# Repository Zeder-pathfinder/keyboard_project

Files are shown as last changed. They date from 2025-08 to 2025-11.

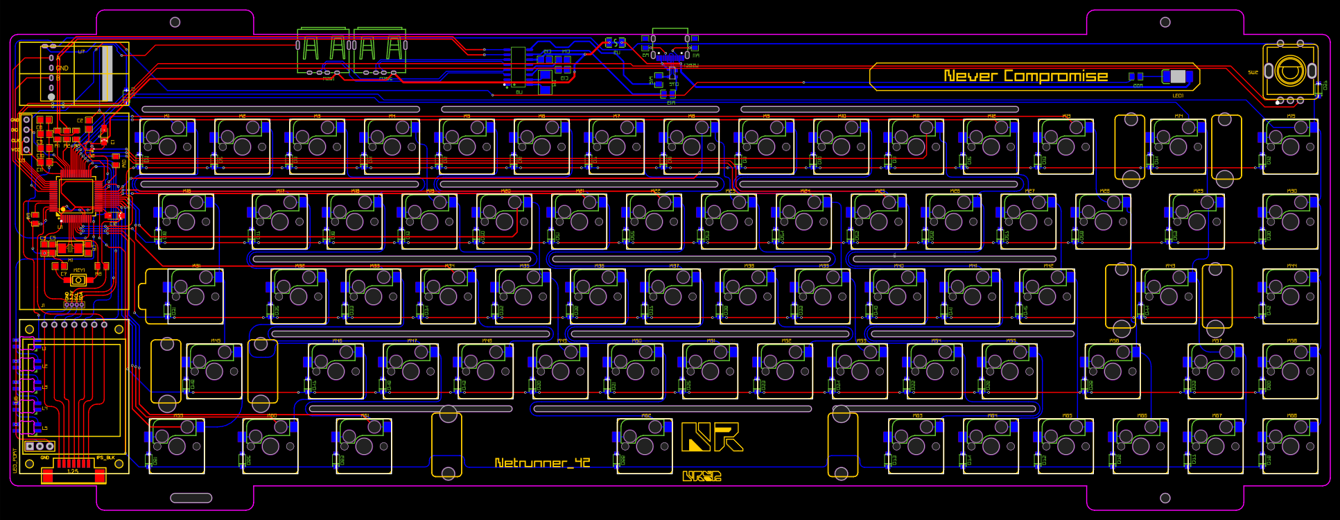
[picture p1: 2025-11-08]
PCB_design/stm32KBD_PCB.png

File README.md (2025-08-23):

# keyboard_project
这个项目是我的一个大学毕业设计。
This project was my university graduation design. 

固件使用的是QMK，但是屏幕的点亮和其它UI设计我不会了，所以烂尾了。
The firmware uses QMK, but I don't know how to light up the screen or do other UI designs, so it ended up unfinished. 

其它功能都是好的，比如键盘上的旋钮，灯光，以及按键。
All other functions work fine，for example, the knobs, lights, and buttons on the keyboard.

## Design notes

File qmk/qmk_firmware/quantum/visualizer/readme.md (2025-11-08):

# A visualization library for the TMK keyboard firmware

This library is designed to work together with the [TMK keyboard firmware](https://github.com/tmk/tmk_keyboard). Currently it only works for [Chibios](http://www.chibios.org/)
 flavors, but it would be possible to add support for other configurations as well. The LCD display functionality is provided by the [uGFX library](http://www.ugfx.org/). 

## To use this library as a user
You can and should modify the visualizer\_user.c file. Check the comments in the file for more information.

## To add this library to custom keyboard projects

1. Add tmk_visualizer as a submodule to your project
1. Set VISUALIZER_DIR in the main keyboard project makefile to point to the submodule
1. Define LCD\_ENABLE and/or LCD\_BACKLIGHT\_ENABLE, to enable support
1. Include the visualizer.mk make file
1. Copy the files in the example\_integration folder to your keyboard project
1. All other files than the callback.c file are included automatically, so you will need to add callback.c to your makefile manually. If you already have a similar file in your project, you can just copy the functions instead of the whole file.
1. Edit the files to match your hardware. You might might want to read the Chibios and UGfx documentation, for more information.
1. If you enable LCD support you might also have to write a custom uGFX display driver, check the uGFX documentation for that. You probably also want to enable SPI support in your Chibios configuration.

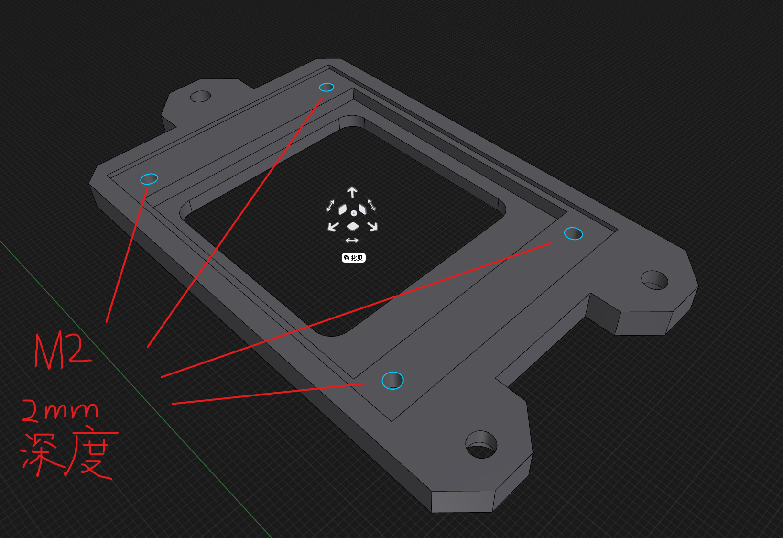
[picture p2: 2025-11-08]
keyboard_model/Screw hole design/Screen bracket screw holes.png

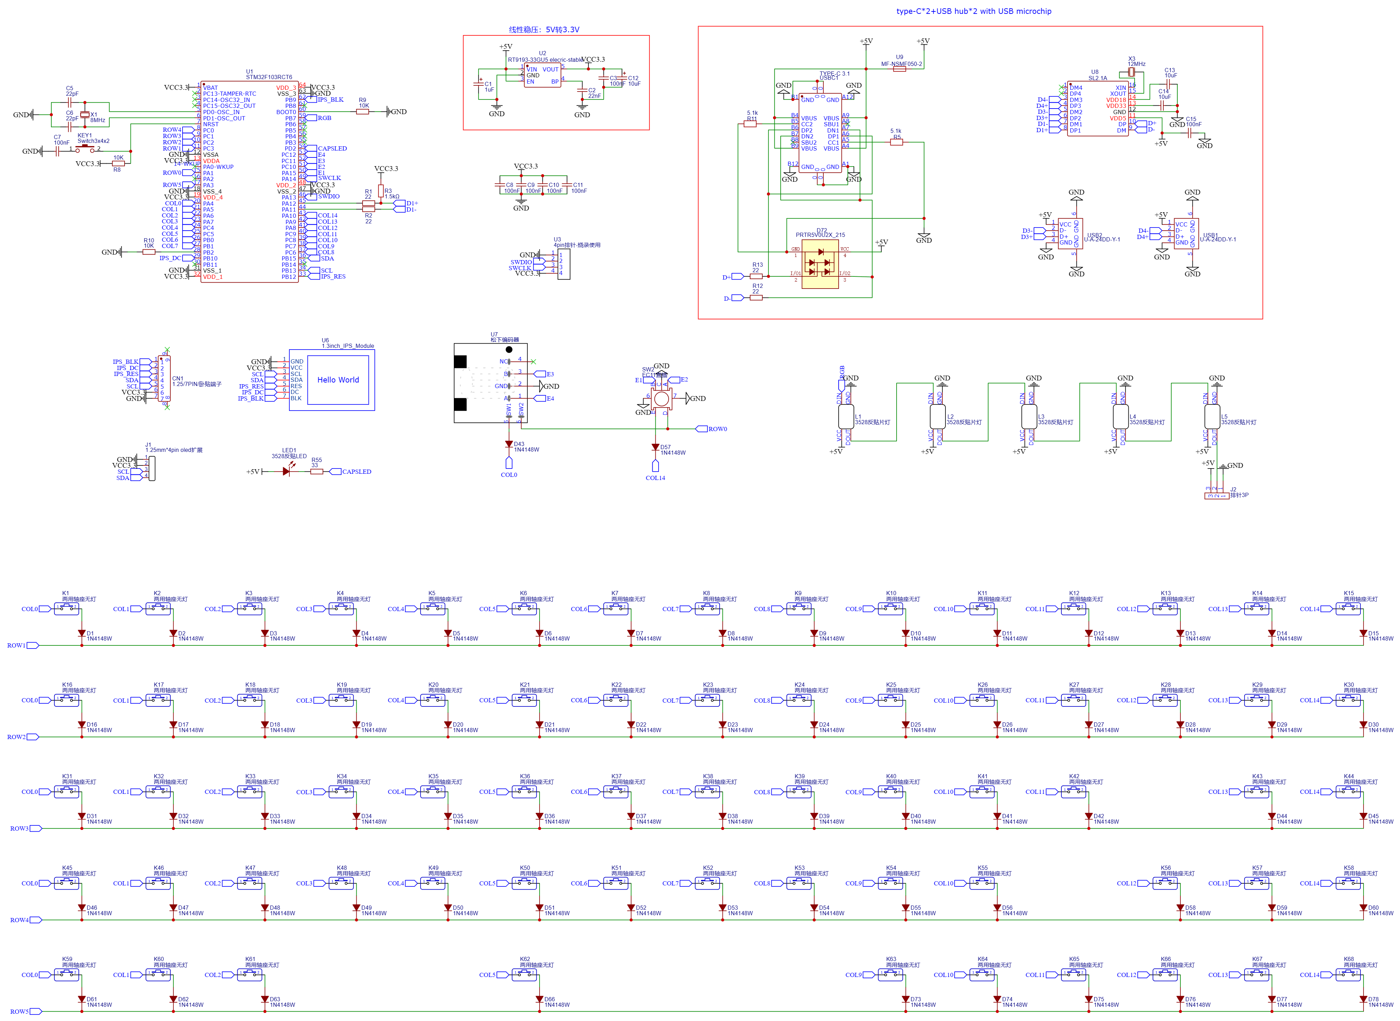
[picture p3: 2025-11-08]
PCB_design/Schematic_netrunner42_stm32_KB_2023-11-25.png

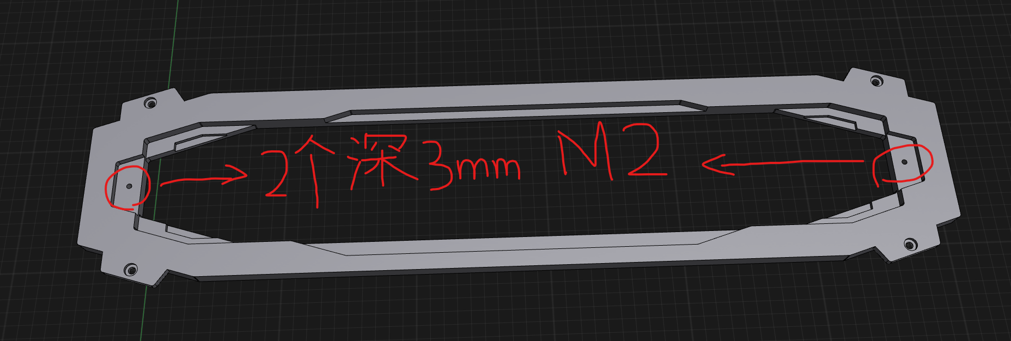
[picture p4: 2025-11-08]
keyboard_model/Screw hole design/Lower display cover hole position.png

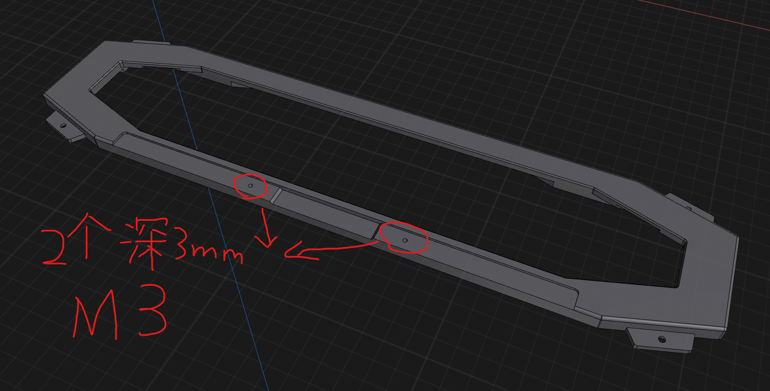
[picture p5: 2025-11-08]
keyboard_model/Screw hole design/bracket screw.png

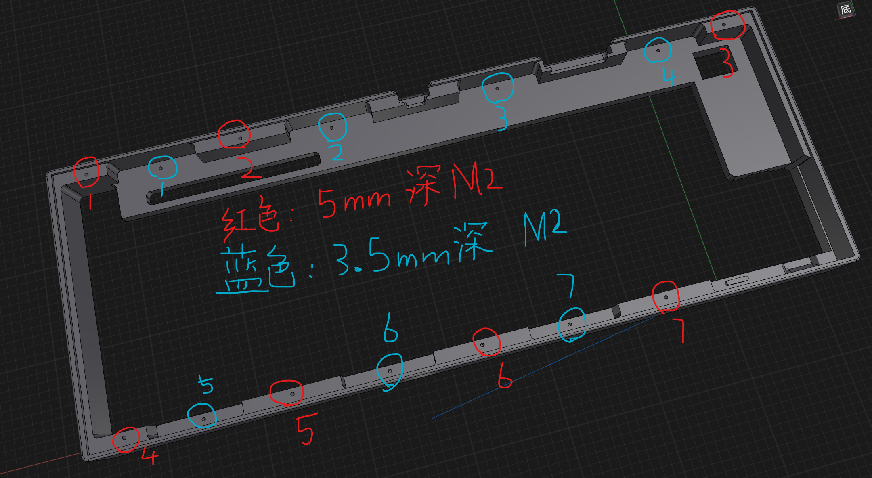
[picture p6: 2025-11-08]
keyboard_model/Screw hole design/Screw hole positions on the bottom of the shell.png

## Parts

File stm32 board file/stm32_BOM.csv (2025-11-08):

ID | Name | Designator | Footprint | Quantity | Manufacturer Part | Manufacturer | Supplier | Supplier Part | Price
1 | 1N4148W | D43,D44,D45,D46,D47,D48,D49,D50,D51,D52,D53,D54,D55,D56,D57,D58,D59,D60,D61,D62,D63,D66,D73,D74,D75,D76,D77,D78,D1,D2,D3,D4,D5,D6,D7,D8,D9,D10,D11,D12,D13,D14,D15,D16,D17,D18,D19,D20,D21,D22,D23,D24,D25,D26,D27,D28,D29,D30,D31,D32,D33,D34,D35,D36,D37,D38,D39,D40,D41,D42 | SOD-123_L2.8-W1.8-LS3.7-RD | 70 | 1N4148W | HT(金誉) | LCSC | C179717 | 0.067
2 | 10uF | C13,C14 | C0805 | 2 | 0805X106K250NT | FH | LCSC | C40894 | 0.084
3 | 100nF | C15 | C0805 | 1 | CC0805KRX7R9BB104 | YAGEO | LCSC | C49678 | 0.0292
4 | PRTR5V0U2X_215 | D72 | 1727-3884-1-ND | 1 | PRTR5V0U2X,215 | Nexperia USA Inc. | DigiKey | 1727-3884-1-ND
5 | 5.1k | R5,R11 | 0805 | 2 | AR06BTCV5101 | Viking Tech | LCSC | C319569 | 0.4251
6 | 22 | R12,R13 | 0805 | 2 | 1206W4F680JT5E |  | Digi-Key | RTAN1206BKE22R0CT-ND
7 | SL2.1A | U8 | SOP-16_L10.0-W3.9-P1.27-LS6.0-BL | 1 | SL2.1A | CoreChips | LCSC | C192893 | 1.4777
8 | MF-NSMF050-2 | U9 | F1206 | 1 | MF-NSMF050-2 | BOURNS | LCSC | C75464 | 0.1672
9 | U-A-24DD-Y-1 | USB1,USB2 | USB-A-TH_U-A-24DD-Y-1 | 2 | U-A-24DD-Y-1 | Rectangular Connectors - Contacts | LCSC | C193133 | 0.8369
10 | 12MHz | X3 | OSC-SMD_2P-L5.0-W3.2 | 1 | 6I12000F20UCG | SHENZHEN CRYSTAL TECH | LCSC | C251588 | 1.7048
11 | TYPE-C 3.1 | USBC1 | USB-C_SMD-TYPE-C-31-M-12 | 1 | - | LCSC | LCSC | C168689 | 3.15
12 | 33 | R55 | R0805 | 1 | RC0805JR-0733RL | YAGEO | LCSC | C127988 | 0.0131
13 | 排针3P | LED_PORT | 排针3P | 1
14 | 3528反贴片灯 | L1,L2,L3,L4,L5 | 凯华RGB | 5
15 | 两用轴座无灯 | K1,K2,K3,K4,K5,K6,K7,K8,K9,K10,K11,K12,K13,K14,K15,K16,K17,K18,K19,K20,K21,K22,K23,K24,K25,K26,K27,K28,K29,K30,K31,K32,K33,K34,K35,K36,K37,K38,K39,K40,K41,K42,K43,K44,K45,K46,K47,K48,K49,K50,K51,K52,K53,K54,K55,K56,K57,K58,K59,K60,K61,K62,K63,K64,K65,K66,K67,K68 | 两用轴座无灯 | 68
16 | 1.3inch_IPS_Module | U6 | 1.3INCH IPS MODULE | 1
17 | 1.25/7PIN/卧贴端子 | CN1 | 1.25/7PIN/卧贴端子 | 1
18 | 1.25mm*4pin oled扩展 | J1 | 1.25*4PIN | 1
19 | STM32F103RCT6 | U1 | LQFP-64_L10.0-W10.0-P0.50-LS12.0-BL | 1 | STM32F103RCT6 | ST(意法半导体) | LCSC | C8323 | 12.06
20 | 4pin排针-烧录使用 | U3 | 4PIN排针 | 1
21 | 松下编码器 | U7 | EVQWGD001 | 1 | EVQWGD001 | panasonic | 77lp | EVQWGD001
22 | 1.5kΩ | R3 | R0805 | 1 | RMC08051.5K1%N | Tyohm(幸亚电阻) | LCSC | C269739 | 0.0309
23 | 3528反贴LED | LED1 | 3528反贴LED | 1 | 204-10SURD/S530-A3 | EVERLIGHT | LCSC | C99772 | 0.1792
24 | EC11直插 | SW2 | SW-TH_EC11E15244G1 | 1 | EC11E15244G1 | ALPS Electric | LCSC | C370970 | 11.73
25 | 1uF | C1 | CAP-SMD_L3.2-W1.6-RD | 1 | TAJA105K025RNJ | AVX | LCSC | C7175 | 0.6411
26 | 22 | R1,R2 | R0805 | 2 | RC0805FR-0722RL | YAGEO | LCSC | C107702 | 0.0128
27 | 8MHz | X1 | CRYSTAL-SMD_L5.0-W3.2 | 1 | X50328MSB2GI | YXC | LCSC | C115962 | 1.1309
28 | 22nF | C2 | C0805 | 1 | CL21B223KBANNNC | SAMSUNG | LCSC | C1729 | 0.0579
29 | 100nF | C3,C7,C8,C9,C10,C11 | C0805 | 6 | CL21B104KBCNNNC | SAMSUNG | LCSC | C1711 | 0.0335
30 | 22pF | C5,C6 | C0805 | 2 | 0805CG220J500NT | FH | LCSC | C38143 | 0.0986
31 | 10uF | C12 | CAP-SMD_L3.2-W1.6-RD | 1 | TAJA106M016RNJ | AVX | LCSC | C8015 | 0.6834
32 | Switch3x4x2 | KEY1 | KEY-3.0*4.0 | 1 | Switch3x4x2 | ReliaPro | LCSC | C26638 | 0.2594
33 | 10K | R8,R9,R10 | R0805 | 3 | RC0805FR-0710KL | YAGEO | LCSC | C84376 | 0.013
34 | RT9193-33GU5 elecric-stable | U2 | SC-70-5_L2.1-W1.3-P0.65-LS2.1-BL | 1 | RT9193-33GU5 | Richtek Tech | LCSC | C425797 | 1.2439

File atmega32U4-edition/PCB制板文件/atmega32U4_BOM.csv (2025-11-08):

ID | Name | Designator | Footprint | Quantity | Manufacturer Part | Manufacturer | Supplier | Supplier Part | Price
1 | 22pF | C1,C2 | C0805 | 2 | 0805CG220J500NT | FH | LCSC | C38143 | 0.0986
2 | 1uF | C3 | C0805 | 1 | CL21B105KBFNFNE | SAMSUNG(三星) | LCSC | C318709 | 0.089
3 | 470nF | C8 | C0805 | 1 | 0805B474K500NT | FH(风华) | LCSC | C49955 | 0.0755
4 | 1N4148W | D2,D3,D4,D5,D6,D7,D8,D9,D10,D11,D12,D13,D14,D15,D16,D17,D18,D19,D20,D21,D22,D23,D24,D25,D26,D27,D28,D29,D30,D31,D32,D33,D34,D35,D36,D37,D38,D39,D40,D41,D42,D43,D44,D45,D46,D47,D48,D49,D50,D51,D52,D53,D54,D55,D56,D57,D58,D59,D60,D61,D62,D63,D64,D65,D66,D67,D68,D69 | SOD-123_L2.8-W1.8-LS3.7-RD | 68 | 1N4148W | HT(金誉) | LCSC | C179717 | 0.067
5 | 10kΩ | R1,R2 | R0805 | 2 | RC0805FR-0710KL | YAGEO(国巨) | LCSC | C84376 | 0.013
6 | 22 | R3,R4 | R0805 | 2 | RC0805FR-0722RL | YAGEO(国巨) | LCSC | C107702 | 0.0128
7 | 5.1K | R6,R7 | R0805 | 2 | RC0805FR-075K1L | YAGEO(国巨) | LCSC | C84375 | 0.0124
8 | TYPE-C-31-M-12 | USBC1 | USB-C_SMD-TYPE-C-31-M-12 | 1 | TYPE-C-31-M-12 | 韩国韩荣 | LCSC | C165948 | 1.0354
9 | 16MHZ | X1 | OSC-SMD_2P-L5.0-W3.2 | 1 | XSHEELNANF-16MHZ | TAITIEN(泰艺电子) | LCSC | C242221 | 2.0561
10 | 100nF | C4,C5,C6,C7 | C0805 | 4 | 0805B104J500NT | FH(风华) | LCSC | C29926 | 0.0506
11 | ATMEGA32U4-AU | MAIN | QFP-44_L10.0-W10.0-P0.80-LS13.2-BL | 1 | ATMEGA32U4-AU | MICROCHIP(美国微芯) | LCSC | C44854 | 35.32
12 | Switch3x4x2 | KEY1 | SW-SMD_L4.0-W2.9-LS5.0 | 1 | 轻触开关3x4x2 | 国产 | LCSC | C26638 | 0.2594
13 | 排针3P | J1 | 排针3P | 1
14 | PCB卫星轴_2.25U | U2,U3,U4 | PCB卫星轴__2.25U | 3
15 | ws2812b-3535 | U5 | WS2812B-3535 | 1

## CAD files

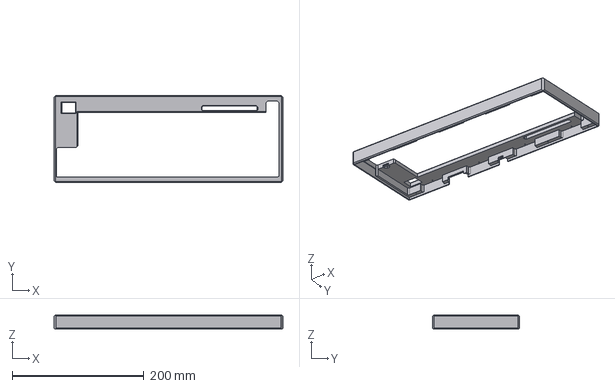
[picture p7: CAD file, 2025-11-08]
atmega32U4-edition/3D打印外壳/upshell.step
347.9 x 132.9 x 21.5 mm

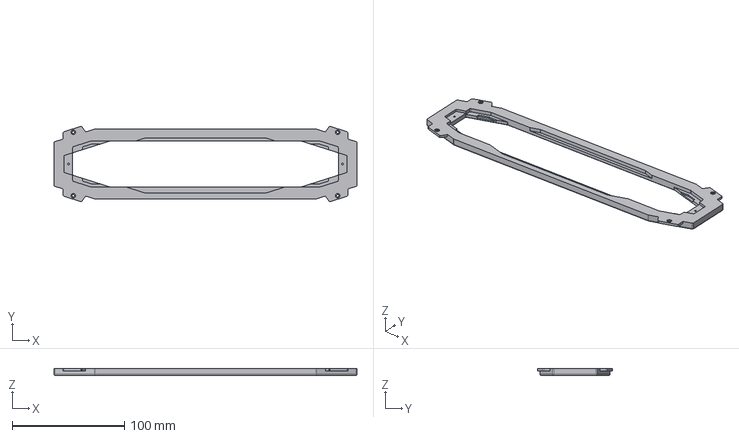
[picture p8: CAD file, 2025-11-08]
keyboard_model/shell2.step
269.7 x 67.1 x 6.00 mm

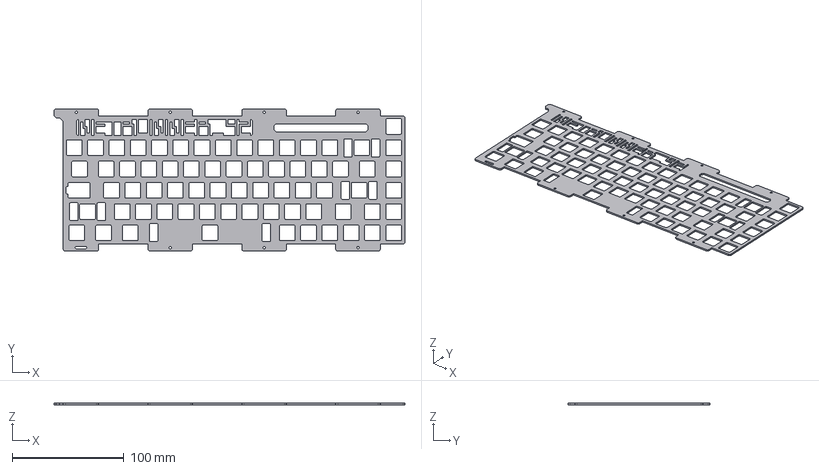
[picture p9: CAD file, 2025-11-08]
atmega32U4-edition/3D打印外壳/plate.step
314.0 x 127.3 x 1.50 mm

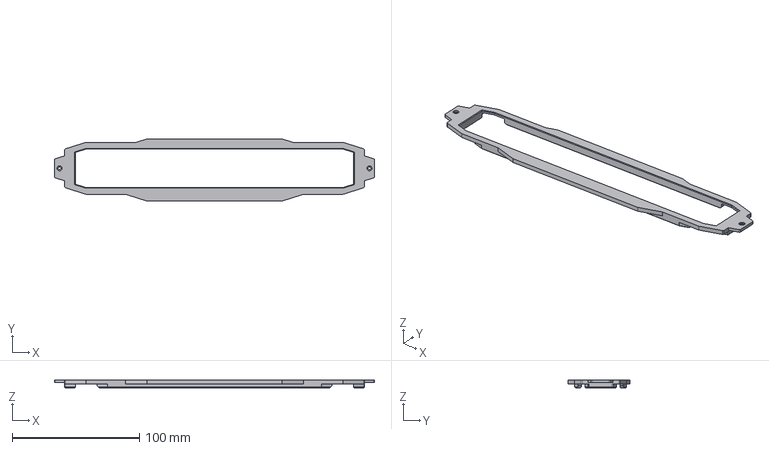
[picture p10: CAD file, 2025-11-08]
keyboard_model/logoshell.step
251.9 x 48.9 x 6.00 mm

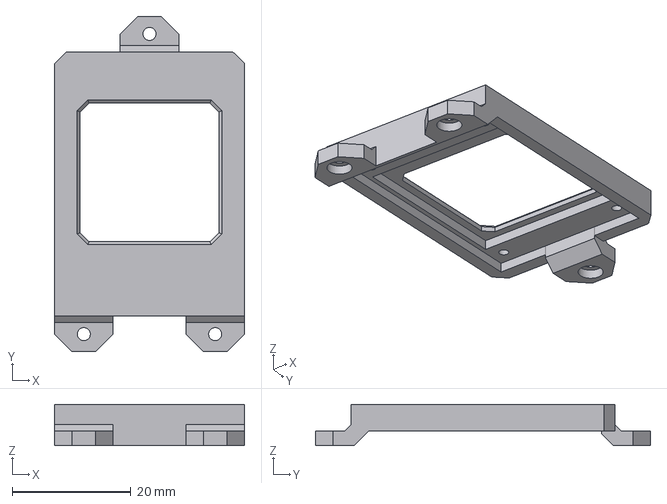
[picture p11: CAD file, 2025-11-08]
atmega32U4-edition/3D打印外壳/screen.step
32.1 x 56.6 x 7.00 mm

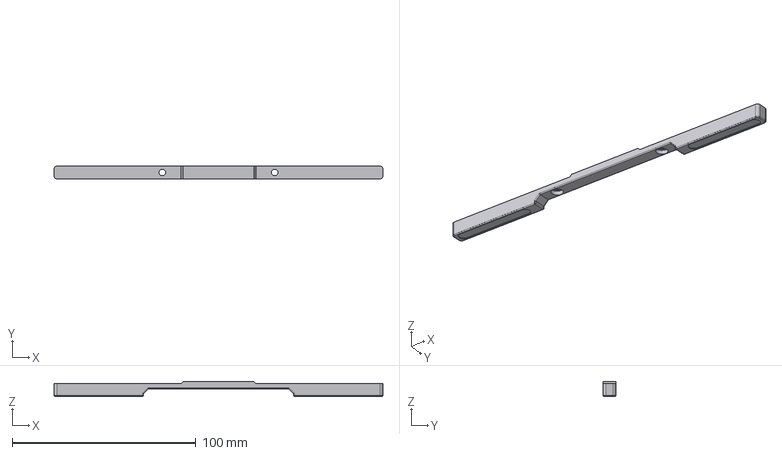
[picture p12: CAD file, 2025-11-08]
keyboard_model/stand.step
179.3 x 6.92 x 8.00 mm

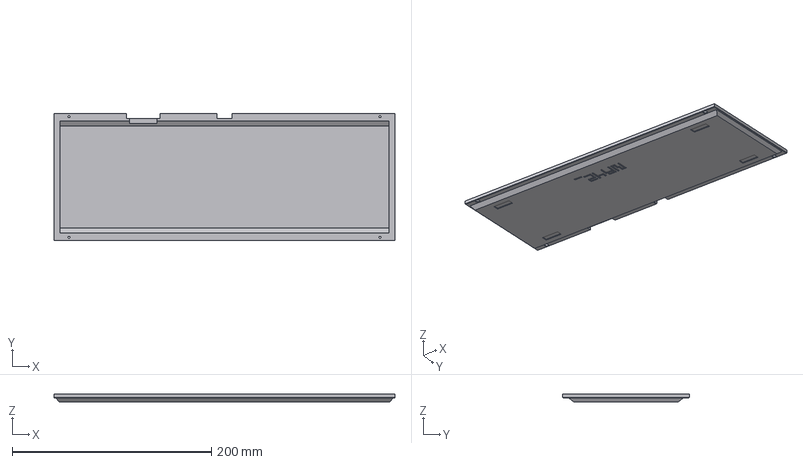
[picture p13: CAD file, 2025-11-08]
atmega32U4-edition/3D打印外壳/downshell.step
341.9 x 127.3 x 8.00 mm

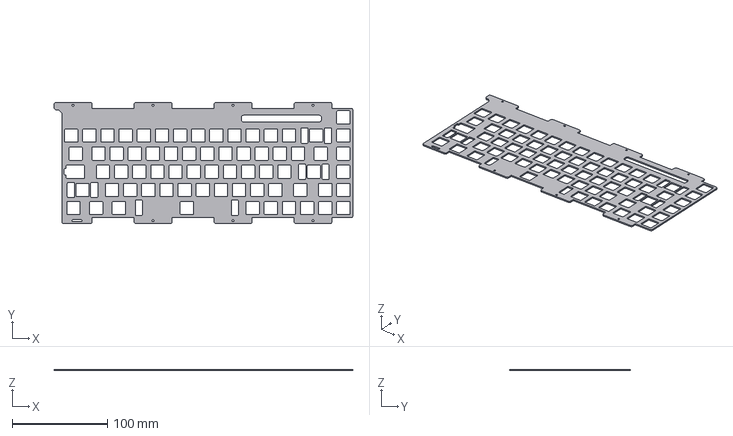
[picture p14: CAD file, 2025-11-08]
keyboard_model/plate.step
314.0 x 127.3 x 1.50 mm

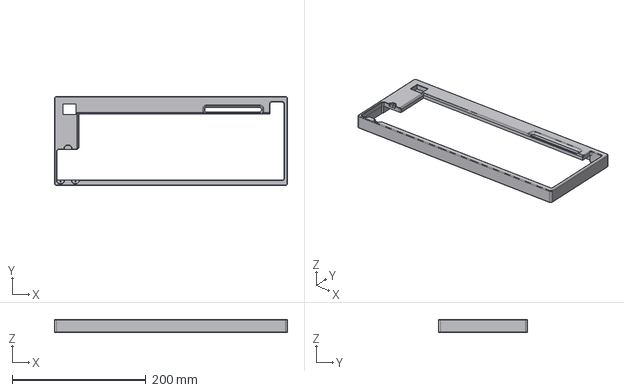
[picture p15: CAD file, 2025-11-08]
keyboard_model/upshell.step
347.9 x 132.9 x 19.5 mm

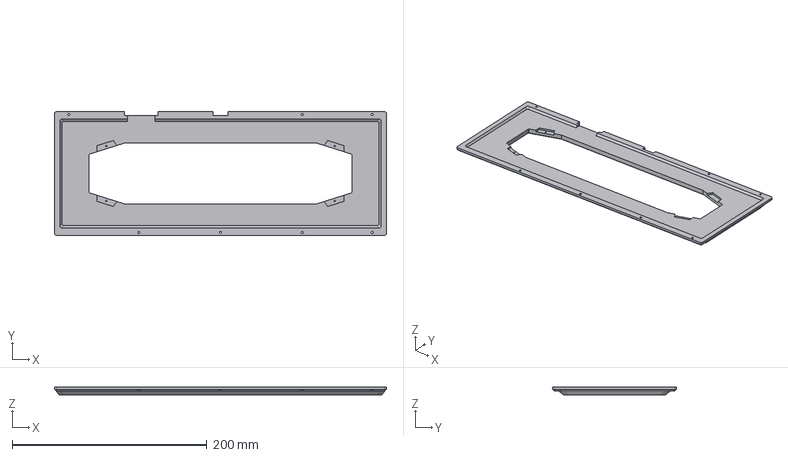
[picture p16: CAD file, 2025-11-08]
keyboard_model/downshell.step
341.3 x 127.3 x 8.00 mm

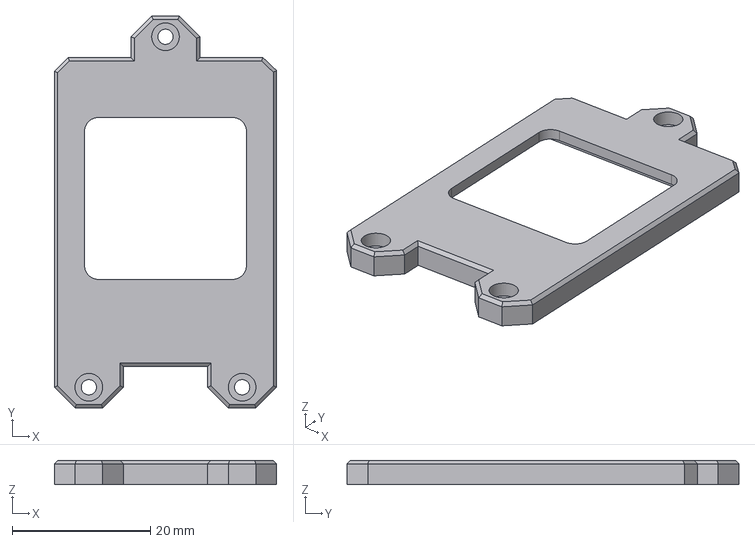
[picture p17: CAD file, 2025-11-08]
keyboard_model/screen.step
32.2 x 56.7 x 3.50 mm

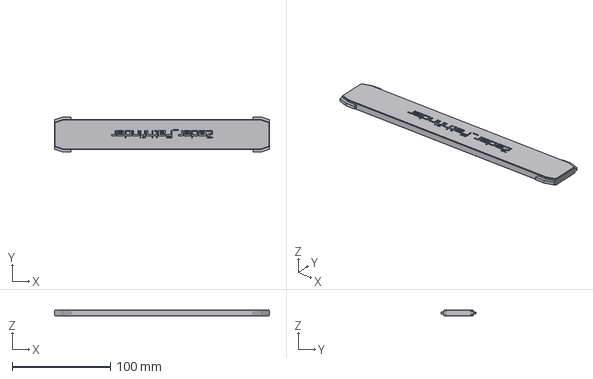
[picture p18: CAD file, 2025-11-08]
keyboard_model/logo.step
218.9 x 35.4 x 6.00 mm

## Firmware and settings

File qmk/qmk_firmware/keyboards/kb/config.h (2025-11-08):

#ifndef CONFIG_H
#define CONFIG_H

#include "config_common.h"

/* USB Device descriptor parameter */
#define VENDOR_ID       0xFEED
#define PRODUCT_ID      0x6060
#define DEVICE_VER      0x0001
#define MANUFACTURER    qmkbuilder
#define PRODUCT         keyboard
#define DESCRIPTION     Keyboard

/* key matrix size */
#define MATRIX_ROWS 6
#define MATRIX_COLS 15

/* key matrix pins */
#define MATRIX_ROW_PINS { B0, B1, B2, B3, B4, B5 }
#define MATRIX_COL_PINS { B6, B7, C0, C1, C2, C3, C4, C5, C6, C7, D0, D1, D2, D3, D4 }
#define UNUSED_PINS

/* COL2ROW or ROW2COL */
#define DIODE_DIRECTION ROW2COL

/* number of backlight levels */

#ifdef BACKLIGHT_PIN
#define BACKLIGHT_LEVELS 3
#endif

/* Set 0 if debouncing isn't needed */
#define DEBOUNCING_DELAY 5

/* Mechanical locking support. Use KC_LCAP, KC_LNUM or KC_LSCR instead in keymap */
#define LOCKING_SUPPORT_ENABLE

/* Locking resynchronize hack */
#define LOCKING_RESYNC_ENABLE

/* key combination for command */
#define IS_COMMAND() ( \
    keyboard_report->mods == (MOD_BIT(KC_LSHIFT) | MOD_BIT(KC_RSHIFT)) \
)

/* prevent stuck modifiers */
#define PREVENT_STUCK_MODIFIERS


#ifdef RGB_DI_PIN
#define RGBLIGHT_ANIMATIONS
#define RGBLED_NUM 70
#define RGBLIGHT_HUE_STEP 8
#define RGBLIGHT_SAT_STEP 8
#define RGBLIGHT_VAL_STEP 8
#endif

#endif

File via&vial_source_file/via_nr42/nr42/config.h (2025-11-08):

#pragma once
//#include "config_common.h"

#define LAYER_STATE_8BIT/*键盘可切换的层*/

/* key matrix size */
#define MATRIX_ROWS 5
#define MATRIX_COLS 15

/* key matrix pins */
#define MATRIX_ROW_PINS { F0, F1, F4, F5, F6 }
#define MATRIX_COL_PINS { C7, C6, D7, D6, D5, D4, D3, D2, D1, D0, B7, B6, B5, B4, B3 }
#define WS2812_DI_PIN B0
#define RGB_MATRIX_LED_COUNT 68
#define RGB_DISABLE_WHEN_USB_SUSPENDED true
#define LED_CAPS_LOCK_PIN E6
#define LED_PIN_ON_STATE 0

/* COL2ROW or ROW2COL */
#define DIODE_DIRECTION ROW2COL/*二极管的朝向*/

/*RGB lights*/
#define DRIVER_LED_TOTAL 69/*total RGB*/
#define RGB_MATRIX_MAXIMUM_BRIGHTNESS 42/*MAX brightness*/
#define RGB_MATRIX_FRAMEBUFFER_EFFECTS
#define RGB_MATRIX_KEYPRESSES/*按键反馈*/
#define ENABLE_RGB_MATRIX_TYPING_HEATMAP
#define RGB_MATRIX_FRAMEBUFFER_EFFECTS
#define ENABLE_RGB_MATRIX_CYCLE_LEFT_RIGHT
#define ENABLE_RGB_MATRIX_CYCLE_UP_DOWN
#define ENABLE_RGB_MATRIX_CYCLE_ALL
#define ENABLE_RGB_MATRIX_SOLID_REACTIVE_SIMPLE

/* Set 0 if debouncing isn't needed */
#define DEBOUNCE 5/*去抖*/

/* Mechanical locking support. Use KC_LCAP, KC_LNUM or KC_LSCR instead in keymap */
#define LOCKING_SUPPORT_ENABLE

/* Locking resynchronize hack */
#define LOCKING_RESYNC_ENABLE
